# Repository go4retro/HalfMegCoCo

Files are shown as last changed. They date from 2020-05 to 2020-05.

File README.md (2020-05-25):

# HalfMegCoCo - an SRAM-based 512kB RAM Expansion for the TANDY Color Computer 3
This printed circuit board implements a very simplistic SRAM-based memory expansion for the Color Computer 3.  All parts are through hole for easy hobbyist assembly. If 512kB x 8 SRAMs are utilized, the unit offers 1MB of RAM expansion, but requires a DAT board from either Boysontech or Cloud9 to utilize the upper 512kB.

## License
Copyright (C) 2020  RETRO Innovations

These files are free designs; you can redistribute them and/or modify
them under the terms of the Creative Commons Attribution-ShareAlike 
4.0 International License.

You should have received a copy of the license along with this
work. If not, see <http://creativecommons.org/licenses/by-sa/4.0/>.

These files are distributed in the hope that they will be useful,
but WITHOUT ANY WARRANTY; without even the implied warranty of
MERCHANTABILITY or FITNESS FOR A PARTICULAR PURPOSE.  See the
license for more details.

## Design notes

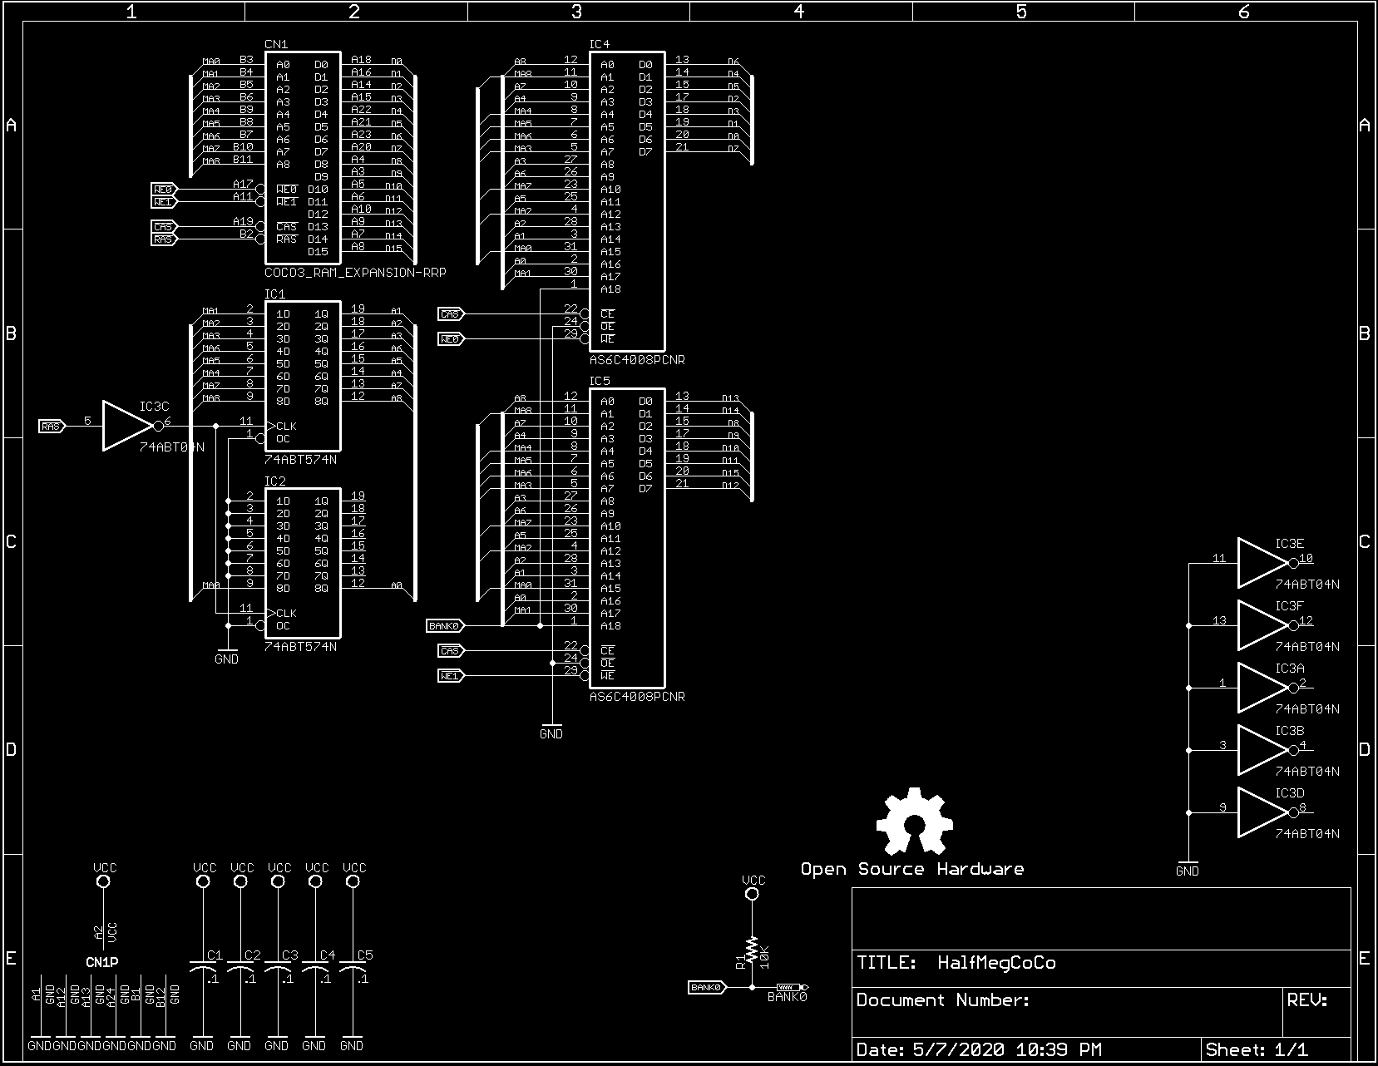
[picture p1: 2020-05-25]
pcb/HalfMegCoCo Schematic.png

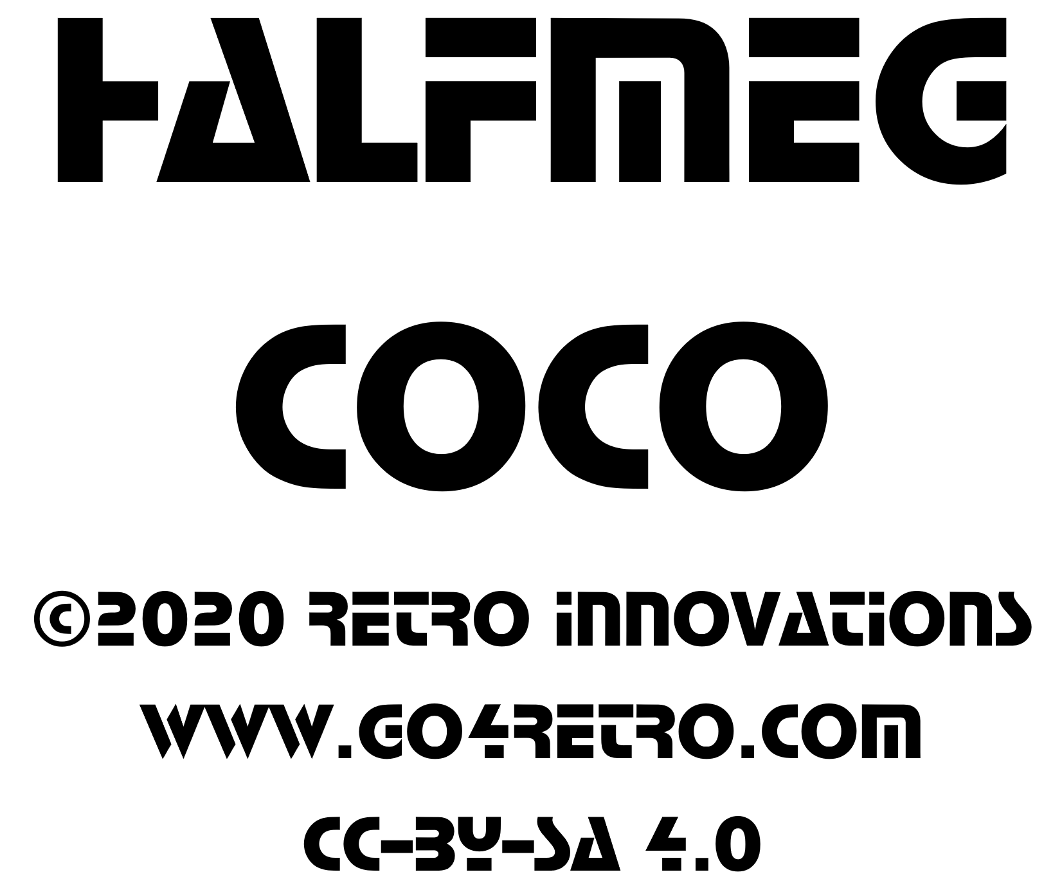
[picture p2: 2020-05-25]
pcb/copyright.PNG

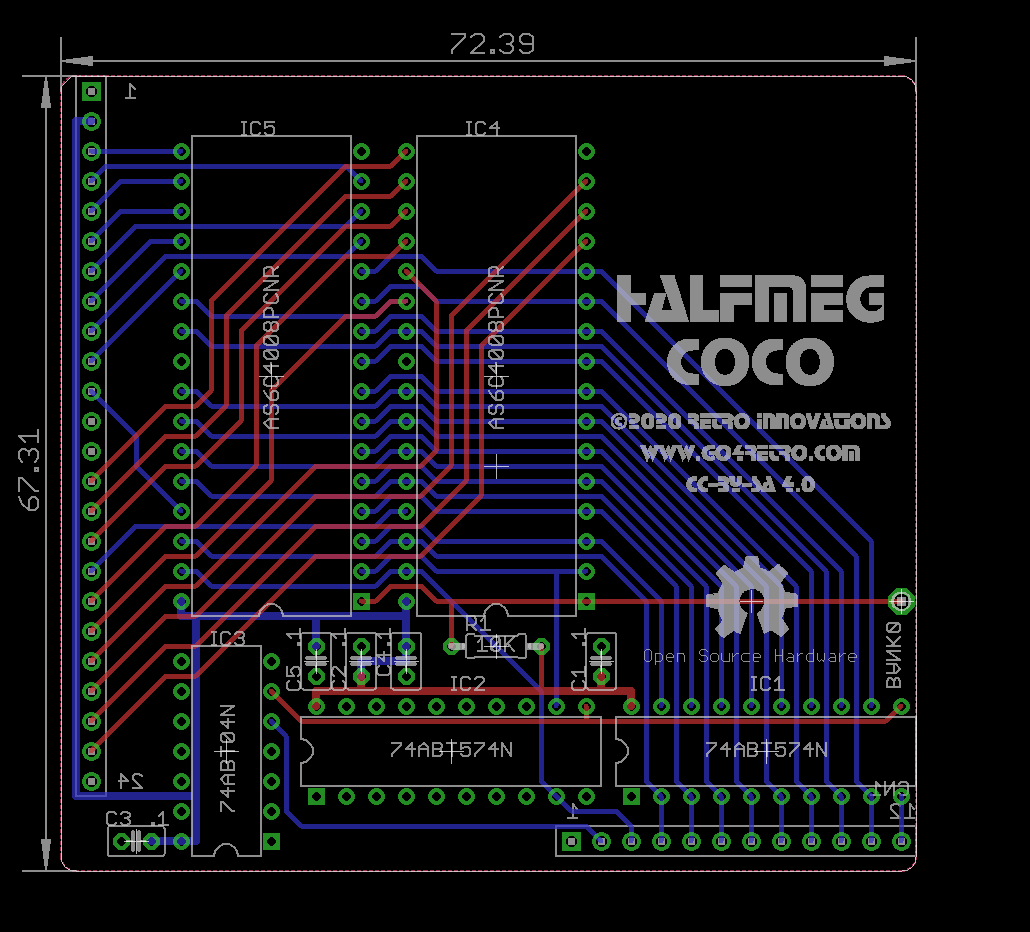
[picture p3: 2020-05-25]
pcb/HalfMegCoCo PCB.png

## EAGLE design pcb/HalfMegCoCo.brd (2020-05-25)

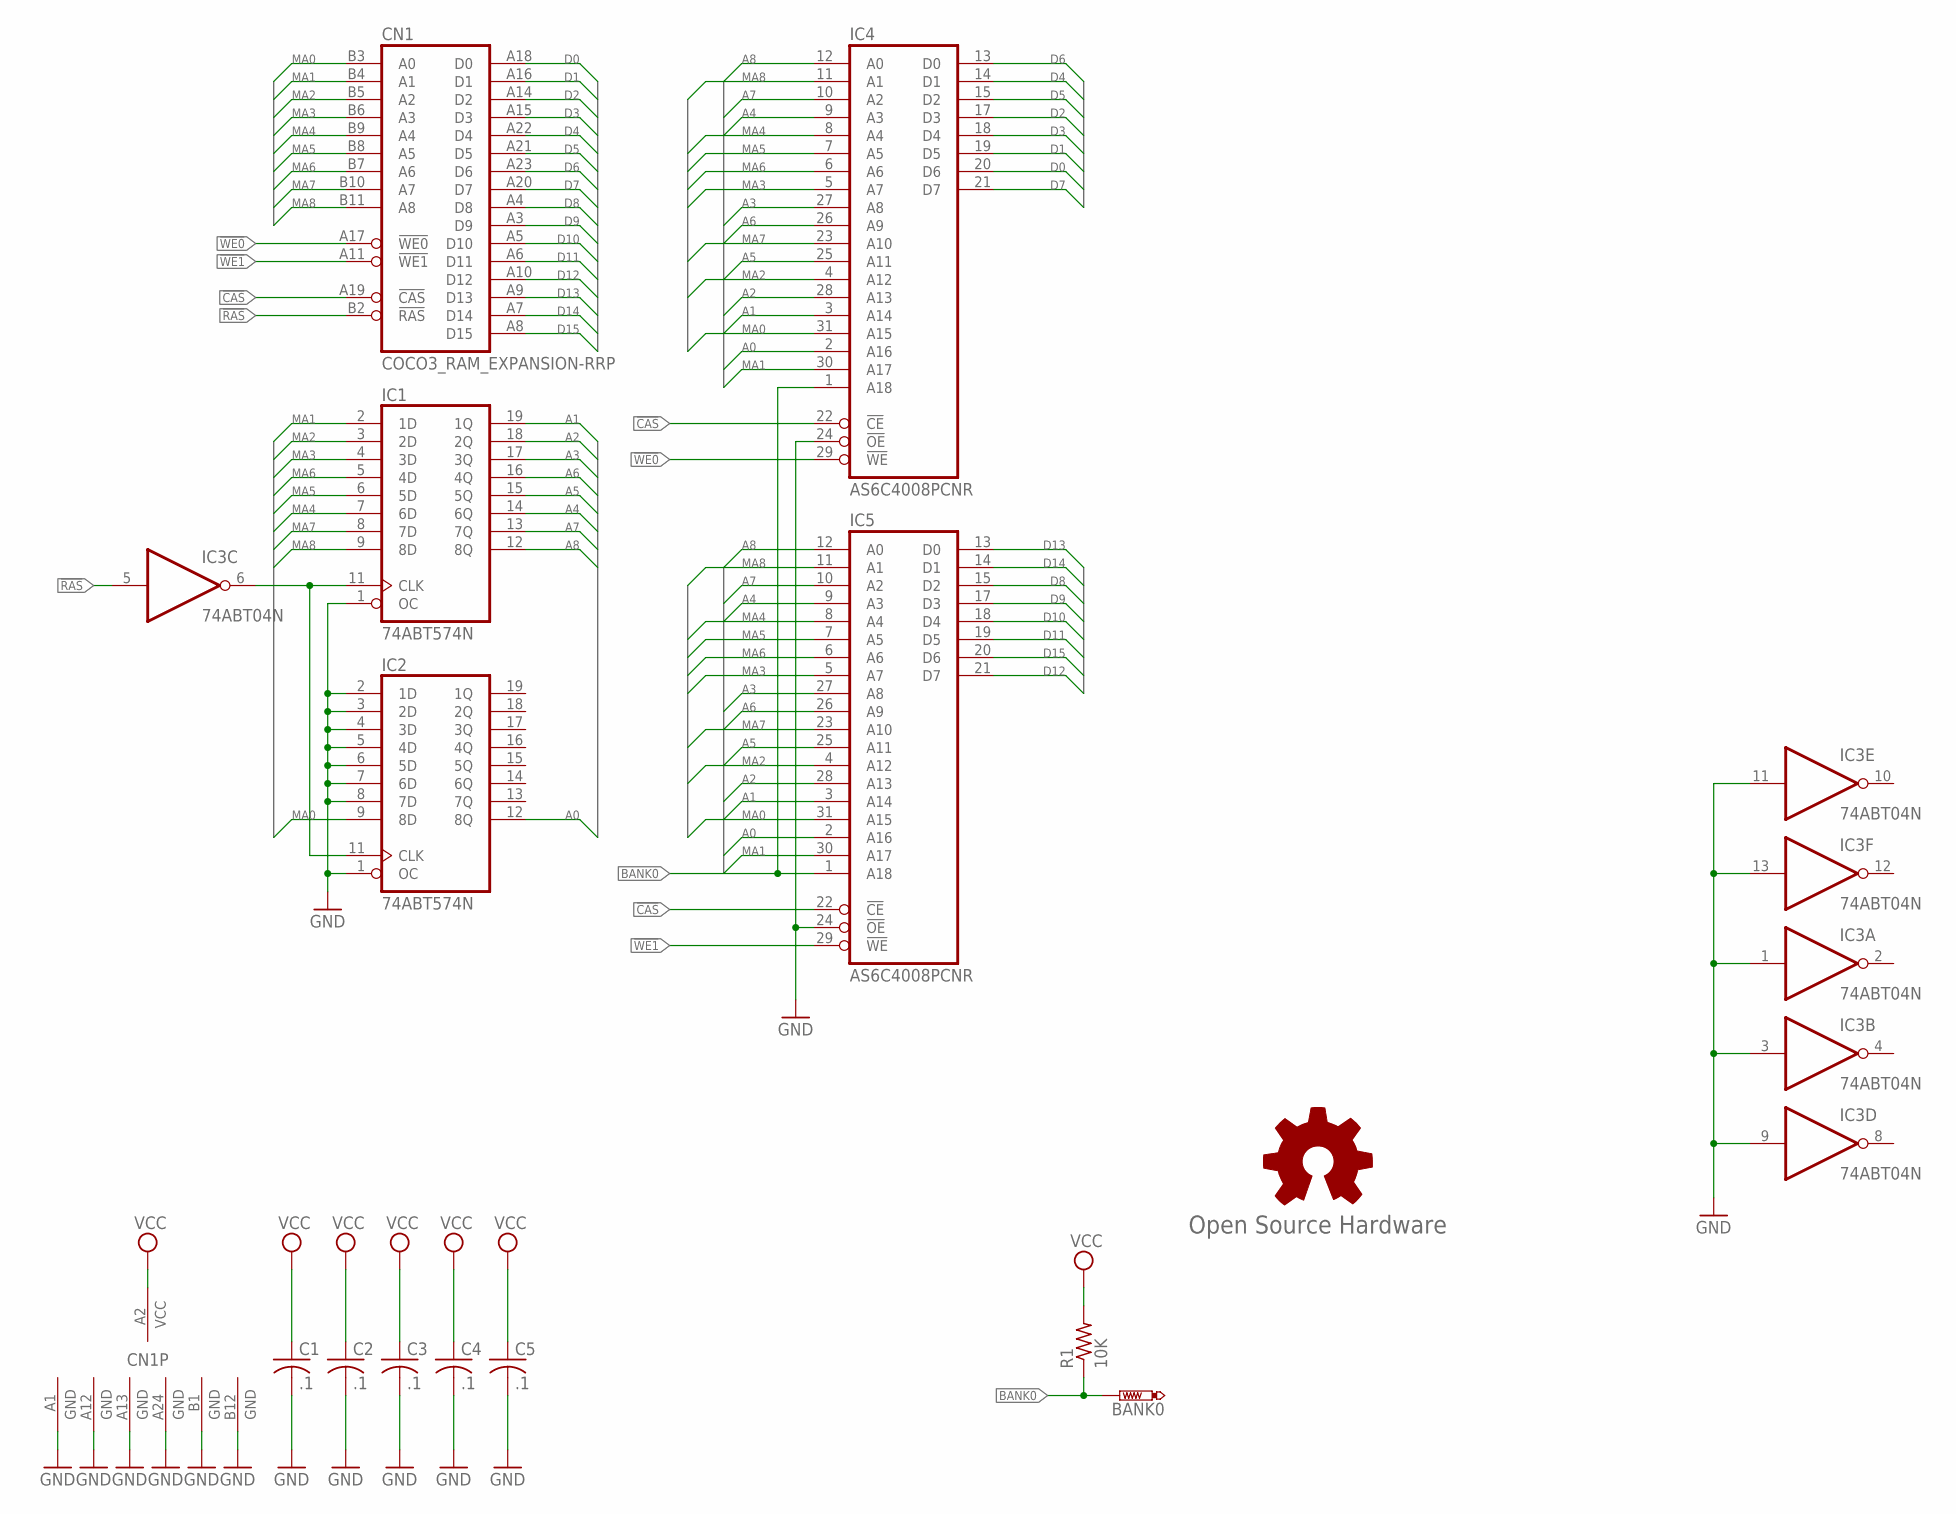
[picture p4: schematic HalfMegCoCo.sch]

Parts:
BANK0: PTR1PAD1-13; P1-13
C1, C2, C3, C4, C5: .1; C025-025X050
CN1: COCO3_RAM_EXPANSION-RRP; RAM_EXPANSION_REV_RP
GOLD_ORB_SM1: Open Source Hardware; OSHW_8MM
IC1, IC2: 74ABT574N; DIL20-RP
IC3: 74ABT04N; DIL14-RP
IC4, IC5: AS6C4008PCNR; DIL32-RP
R1: 10K; 0204/7

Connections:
!CAS: CN1.A19 (!CAS), IC4.22 (!CE), IC5.22 (!CE)
!RAS: CN1.B2 (!RAS), IC3.5 (I)
!WE0: CN1.A17 (!WE0), IC4.29 (!WE)
!WE1: CN1.A11 (!WE1), IC5.29 (!WE)
A0: IC2.12 (8Q), IC4.2 (A16), IC5.2 (A16)
A1: IC1.19 (1Q), IC4.3 (A14), IC5.3 (A14)
A2: IC1.18 (2Q), IC4.28 (A13), IC5.28 (A13)
A3: IC1.17 (3Q), IC4.27 (A8), IC5.27 (A8)
A4: IC1.14 (6Q), IC4.9 (A3), IC5.9 (A3)
A5: IC1.15 (5Q), IC4.25 (A11), IC5.25 (A11)
A6: IC1.16 (4Q), IC4.26 (A9), IC5.26 (A9)
A7: IC1.13 (7Q), IC4.10 (A2), IC5.10 (A2)
A8: IC1.12 (8Q), IC4.12 (A0), IC5.12 (A0)
BANK0: BANK0.TP, IC4.1 (A18), IC5.1 (A18), R1.1
D0: CN1.A18 (D0), IC4.20 (D6)
D1: CN1.A16 (D1), IC4.19 (D5)
D2: CN1.A14 (D2), IC4.17 (D3)
D3: CN1.A15 (D3), IC4.18 (D4)
D4: CN1.A22 (D4), IC4.14 (D1)
D5: CN1.A21 (D5), IC4.15 (D2)
D6: CN1.A23 (D6), IC4.13 (D0)
D7: CN1.A20 (D7), IC4.21 (D7)
D8: CN1.A4 (D8), IC5.15 (D2)
D9: CN1.A3 (D9), IC5.17 (D3)
D10: CN1.A5 (D10), IC5.18 (D4)
D11: CN1.A6 (D11), IC5.19 (D5)
D12: CN1.A10 (D12), IC5.21 (D7)
D13: CN1.A9 (D13), IC5.13 (D0)
D14: CN1.A7 (D14), IC5.14 (D1)
D15: CN1.A8 (D15), IC5.20 (D6)
GND: C1.2, C2.2, C3.2, C4.2, C5.2, CN1.A1 (GND), CN1.A12 (GND), CN1.A13 (GND), CN1.A24 (GND), CN1.B1 (GND), CN1.B12 (GND), IC1.1 (OC), IC1.10 (GND), IC2.1 (OC), IC2.2 (1D), IC2.3 (2D), IC2.4 (3D), IC2.5 (4D), IC2.6 (5D), IC2.7 (6D), IC2.8 (7D), IC2.10 (GND), IC3.1 (I), IC3.3 (I), IC3.7 (GND), IC3.9 (I), IC3.11 (I), IC3.13 (I), IC4.16 (GND), IC4.24 (!OE), IC5.16 (GND), IC5.24 (!OE)
MA0: CN1.B3 (A0), IC2.9 (8D), IC4.31 (A15), IC5.31 (A15)
MA1: CN1.B4 (A1), IC1.2 (1D), IC4.30 (A17), IC5.30 (A17)
MA2: CN1.B5 (A2), IC1.3 (2D), IC4.4 (A12), IC5.4 (A12)
MA3: CN1.B6 (A3), IC1.4 (3D), IC4.5 (A7), IC5.5 (A7)
MA4: CN1.B9 (A4), IC1.7 (6D), IC4.8 (A4), IC5.8 (A4)
MA5: CN1.B8 (A5), IC1.6 (5D), IC4.7 (A5), IC5.7 (A5)
MA6: CN1.B7 (A6), IC1.5 (4D), IC4.6 (A6), IC5.6 (A6)
MA7: CN1.B10 (A7), IC1.8 (7D), IC4.23 (A10), IC5.23 (A10)
MA8: CN1.B11 (A8), IC1.9 (8D), IC4.11 (A1), IC5.11 (A1)
unnamed: IC1.11 (CLK), IC2.11 (CLK), IC3.6 (O)
VCC: C1.1, C2.1, C3.1, C4.1, C5.1, CN1.A2 (VCC), IC1.20 (VCC), IC2.20 (VCC), IC3.14 (VCC), IC4.32 (VCC), IC5.32 (VCC), R1.2

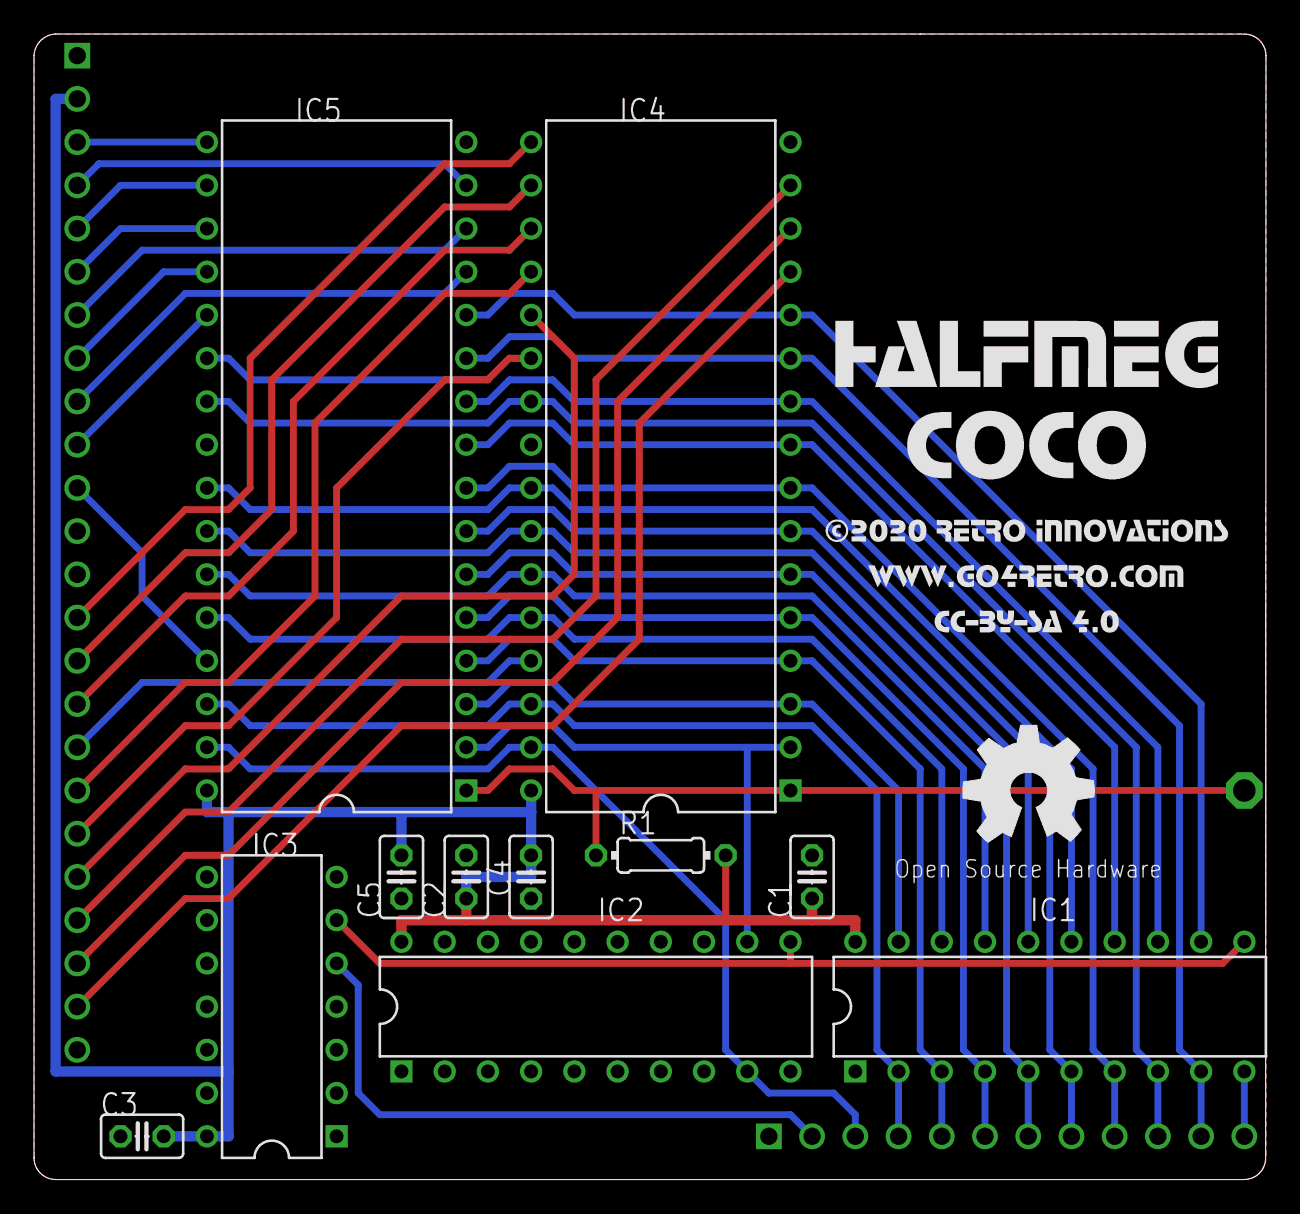
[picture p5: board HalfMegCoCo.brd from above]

Board: 2 copper layers, 72.4 x 67.3 mm, 14 parts (0 on the bottom side), 42 nets.

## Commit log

2020-03-03 Fixed filename
    [HalfMegCoCo.brd, HalfMegCoCo_ZIP.sch]
2020-05-25 SRAM-based version added, DRAM version removed.
    [HalfMegCoCo.brd, HalfMegCoCo.sch]
2020-05-25 Cleaned up Copyright bitmap files
    [HalfMegCoCo_ZIP.brd, HalfMegCoCo_ZIP.sch]
